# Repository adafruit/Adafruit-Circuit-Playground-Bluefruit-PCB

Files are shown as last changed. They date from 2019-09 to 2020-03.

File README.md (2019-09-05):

## Adafruit Adafruit Circuit Playground Bluefruit PCB

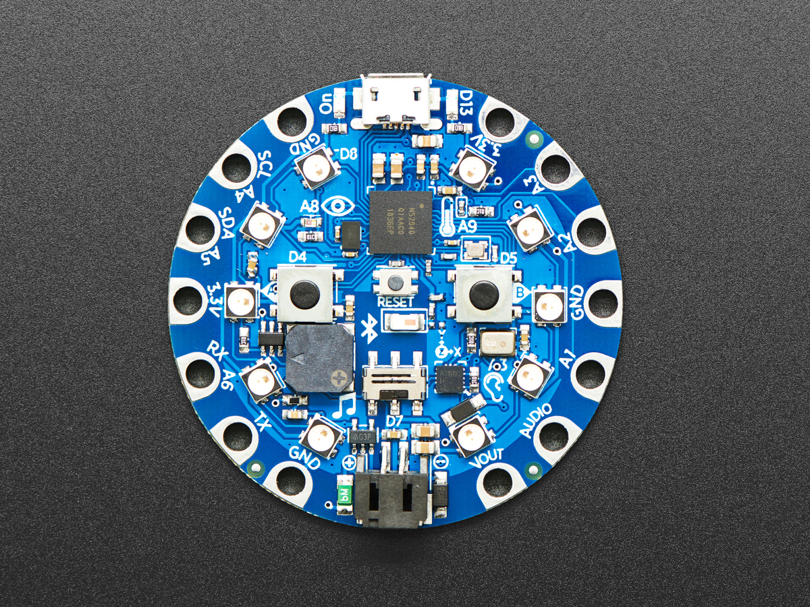
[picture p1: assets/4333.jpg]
<a href="http://www.adafruit.com/products/4333"><br/>
Click here to purchase one from the Adafruit shop</a>

PCB files for the Adafruit Adafruit Circuit Playground Bluefruit. 

Format is EagleCAD schematic and board layout
* https://www.adafruit.com/product/4333

### Description

Circuit Playground Bluefruit is our third board in the Circuit Playground series, another step towards a perfect introduction to electronics and programming. We've taken the popular Circuit Playground Express and made it even better! Now the main chip is an nRF52840 microcontroller which is not only more powerful, but also comes with Bluetooth Low Energy support for wireless connectivity.

The board is round and has alligator-clip pads around it so you don't have to solder or sew to make it work. You can power it from USB, a AAA battery pack, or with a Lipoly battery (for advanced users). Circuit Playground Bluefruit has built-in USB support. Built in USB means you plug it in to program it and it just shows up, no special cable or adapter required. Just program your code into the board then take it on the go!

Here's some of the great goodies baked in to each Circuit Playground Bluefruit:

* 1 x nRF52840 Cortex M4 processor with Bluetooth Low Energy support
* 10 x mini NeoPixels, each one can display any color
* 1 x Motion sensor (LIS3DH triple-axis accelerometer with tap detection, free-fall detection)
* 1 x Temperature sensor (thermistor)
* 1 x Light sensor (phototransistor). Can also act as a color sensor and pulse sensor.
* 1 x Sound sensor (MEMS microphone)
* 1 x Mini speaker with class D amplifier (7.5mm magnetic speaker/buzzer)
* 2 x Push buttons, labeled A and B
* 1 x Slide switch
* 8 x alligator-clip friendly input/output pins
* Includes I2C, UART, 6 pins that can do analog inputs, multiple PWM outputs
* Green "ON" LED so you know its powered
* Red "#13" LED for basic blinking
* Reset button
* 2 MB of SPI Flash storage, used primarily with CircuitPython to store code and libraries.
* MicroUSB port for programming and debugging
* USB port can act like serial port, keyboard, mouse, joystick or MIDI!

### License

Adafruit invests time and resources providing this open source design, please support Adafruit and open-source hardware by purchasing products from [Adafruit](https://www.adafruit.com)!

Designed by Limor Fried/Ladyada for Adafruit Industries.

Creative Commons Attribution/Share-Alike, all text above must be included in any redistribution. 
See license.txt for additional details.

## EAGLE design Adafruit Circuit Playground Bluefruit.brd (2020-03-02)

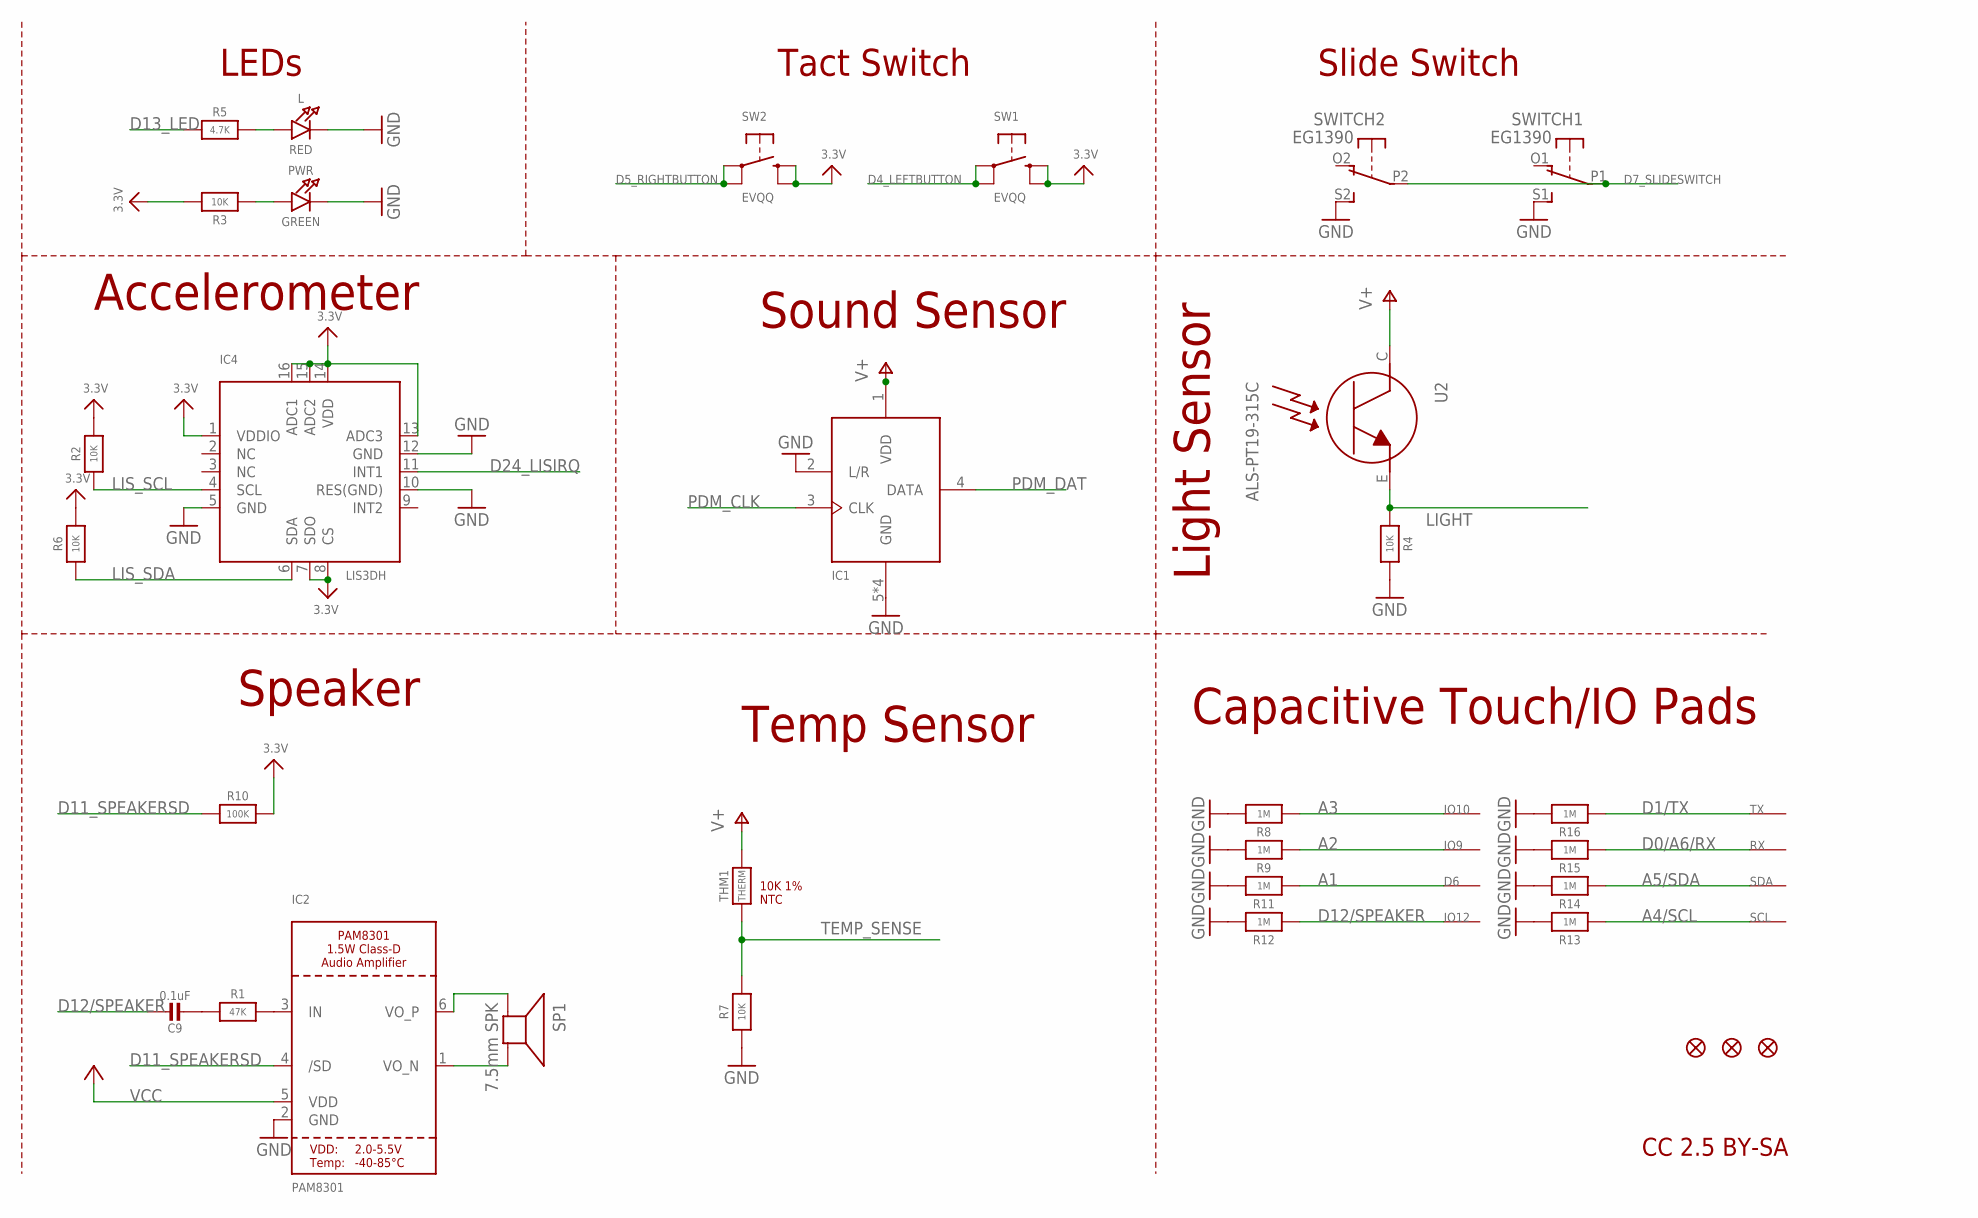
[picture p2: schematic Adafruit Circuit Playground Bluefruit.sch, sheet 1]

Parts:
C9: 0.1uF; 0603-NO
D6: SEWTAP-ALLIGATOR; SEWALLI
IC1: MIC_PDM; SPK0415HM4H
IC2: PAM8301; SOT23-6
IC4: LIS3DH; LGA16_3X3MM
IO9, IO10, IO12: SEWTAP-ALLIGATOR; SEWALLI
L: RED; CHIPLED_0603_NOOUTLINE
PWR: GREEN; CHIPLED_0603_NOOUTLINE
R1: 47K; 0603-NO
R2, R3, R4, R6, R7: 10K; 0603-NO
R5: 4.7K; 0603-NO
R8, R9, R11, R12, R13, R14, R15, R16: 1M; 0603-NO
R10: 100K; 0603-NO
RX: SEWTAP-ALLIGATOR; SEWALLI
SCL: SEWTAP-ALLIGATOR; SEWALLI
SDA: SEWTAP-ALLIGATOR; SEWALLI
SP1: 7.5mm SPK; BUZZER_SMT_7.5MM
SW1, SW2: EVQQ; EVQ-Q2_SMALLER
SWITCH: EG1390
THM1: THERM; _0402
TX: SEWTAP-ALLIGATOR; SEWALLI
U2: ALS-PT19-315C
U$2, U$3, U$6: FIDUCIAL_1MM

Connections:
3.3V: IC4.1 (VDDIO), IC4.7 (SDO), IC4.8 (CS), IC4.13 (ADC3), IC4.14 (VDD), IC4.15 (ADC2), IC4.16 (ADC1), R2.2, R3.2, R6.2, R10.2, SW1.B (S), SW1.B' (S1), SW2.B (S), SW2.B' (S1); also elsewhere on the board
A1: D6.P$1, R11.1; also elsewhere on the board
A2: IO9.P$1, R9.1; also elsewhere on the board
A3: IO10.P$1, R8.1; also elsewhere on the board
A4/SCL: R13.1, SCL.P$1; also elsewhere on the board
A5/SDA: R14.1, SDA.P$1; also elsewhere on the board
D0/A6/RX: R15.1, RX.P$1; also elsewhere on the board
D1/TX: R16.1, TX.P$1; also elsewhere on the board
D4_LEFTBUTTON: SW1.A, SW1.A' (P1); also elsewhere on the board
D5_RIGHTBUTTON: SW2.A, SW2.A' (P1); also elsewhere on the board
D7_SLIDESWITCH: SWITCH.P1, SWITCH.P2; also elsewhere on the board
D11_SPEAKERSD: IC2.4 (/SD), R10.1; also elsewhere on the board
D12/SPEAKER: C9.1, IO12.P$1, R12.1; also elsewhere on the board
D13_LED: R5.1; also elsewhere on the board
D24_LISIRQ: IC4.11 (INT1); also elsewhere on the board
GND: IC1.2 (L/R), IC1.5 (GND), IC1.6 (GND), IC1.7 (GND), IC1.8 (GND), IC2.2 (GND), IC4.5 (GND), IC4.10 (RES(GND)), IC4.12 (GND), L.C, PWR.C, R4.1, R7.1, R8.2, R9.2, R11.2, R12.2, R13.2, R14.2, R15.2, R16.2, SWITCH.S1 (S), SWITCH.S2 (S); also elsewhere on the board
LIGHT: R4.2, U2.E; also elsewhere on the board
LIS_SCL: IC4.4 (SCL), R2.1; also elsewhere on the board
LIS_SDA: IC4.6 (SDA), R6.1; also elsewhere on the board
unnamed: PWR.A, R3.1
unnamed: C9.2, R1.1
unnamed: IC2.3 (IN), R1.2
unnamed: IC2.6 (VO_P), SP1.+
unnamed: L.A, R5.2
unnamed: IC2.1 (VO_N), SP1.-
PDM_CLK: IC1.3 (CLK); also elsewhere on the board
PDM_DAT: IC1.4 (DATA); also elsewhere on the board
TEMP_SENSE: R7.2, THM1.1; also elsewhere on the board
V+: IC1.1 (VDD), THM1.2, U2.C; also elsewhere on the board
VCC: IC2.5 (VDD); also elsewhere on the board

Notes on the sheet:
CC 2.5 BY-SA
10K 1% NTC
Speaker
Temp Sensor
Light Sensor
Sound Sensor
Slide Switch
Tact Switch
LEDs
Accelerometer
Capacitive Touch/IO Pads

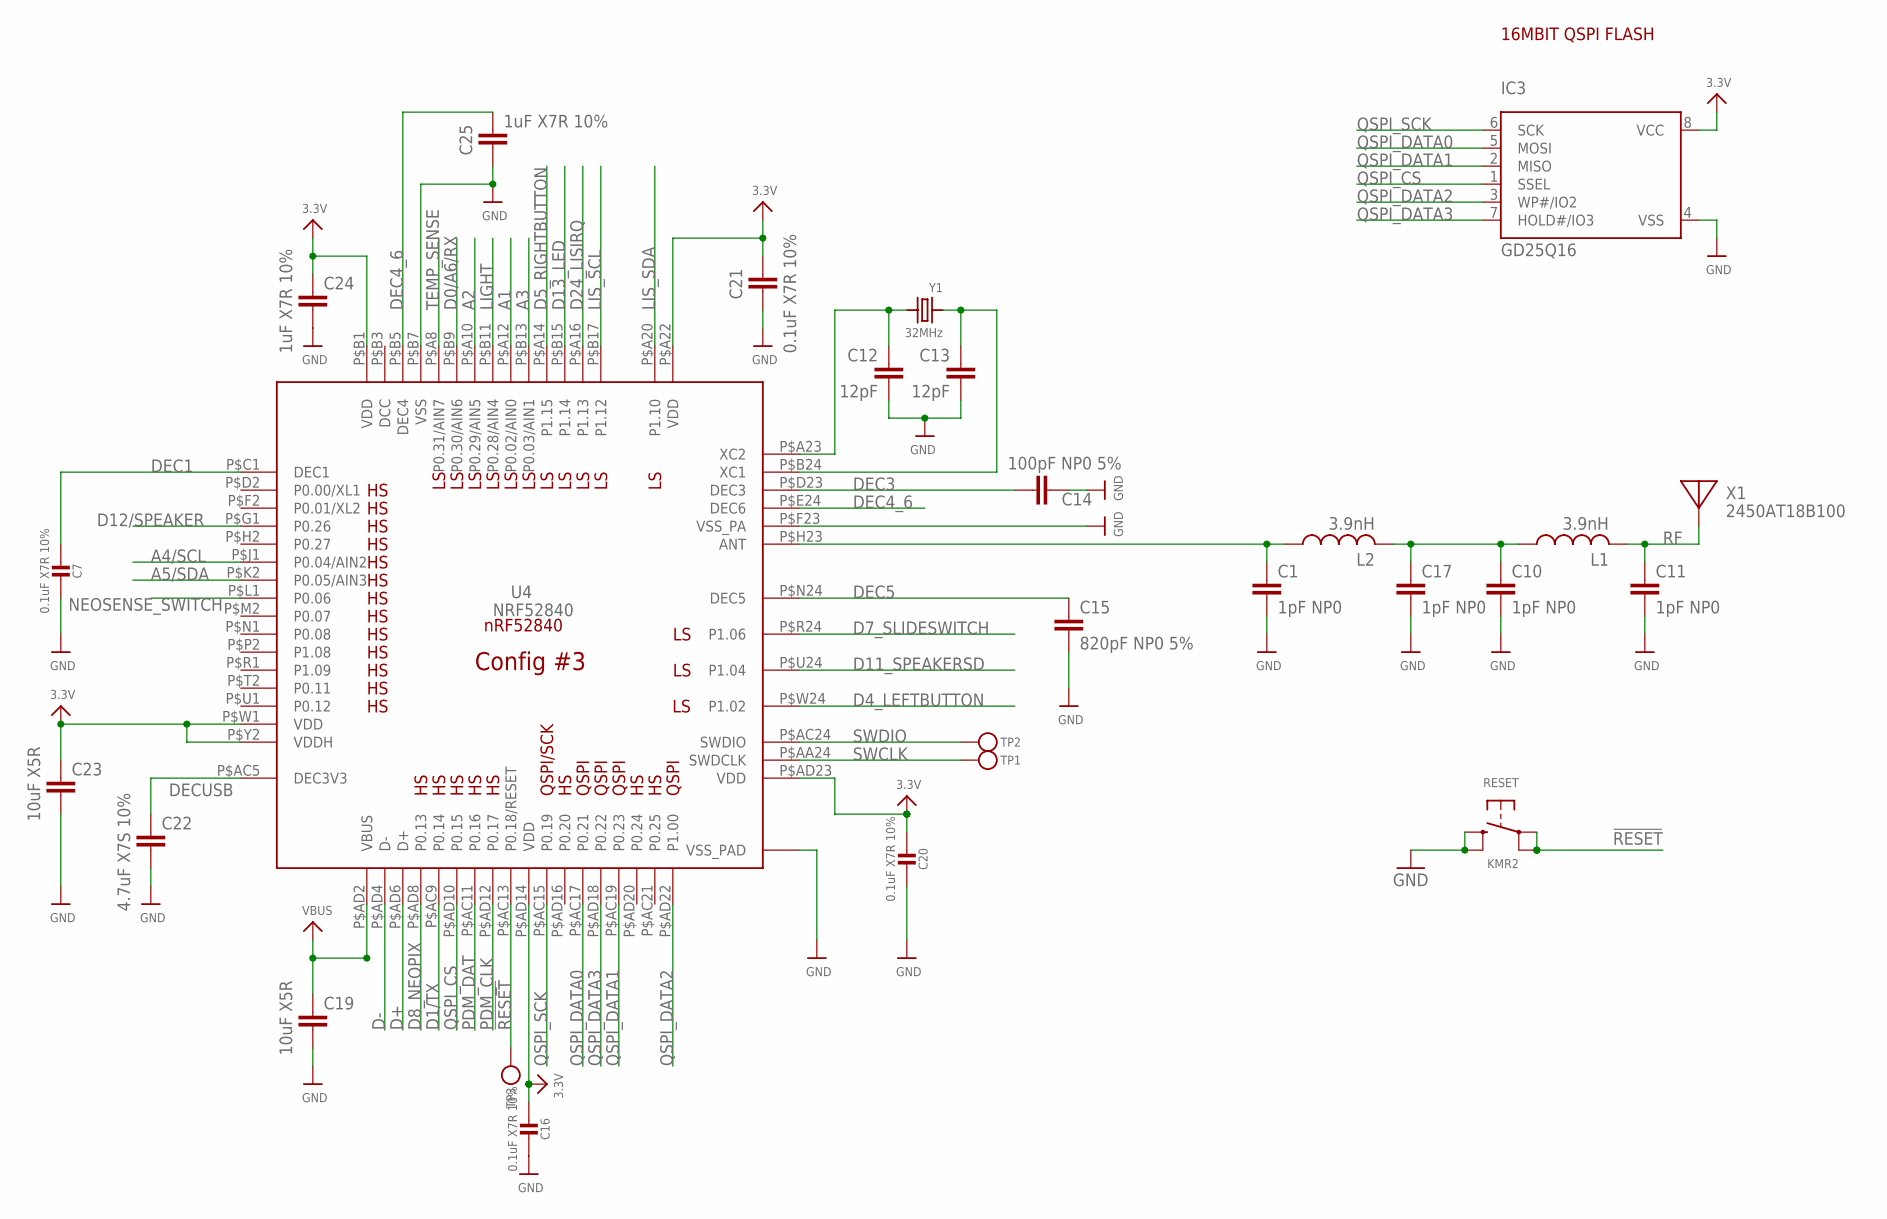
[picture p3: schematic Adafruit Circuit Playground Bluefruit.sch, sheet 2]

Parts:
C1, C10, C11, C17: 1pF NP0; RESC0402_N
C7, C16, C20: 0.1uF X7R 10%; 0603-NO
C12, C13: 12pF; RESC0402_N
C14: 100pF NP0 5%; RESC0402_N
C15: 820pF NP0 5%; RESC0402_N
C19, C23: 10uF X5R; RESC0805_N
C21: 0.1uF X7R 10%; RESC0603_L
C22: 4.7uF X7S 10%; RESC0805_N
C24, C25: 1uF X7R 10%; RESC0603_N
IC3: GD25Q16; USON8
L1, L2: 3.9nH; RESC0402_N
RESET: KMR2; BTN_KMR2_4.6X2.8
TP1, TP2, TP3: TESTPOINTROUND1.5MMNO; TESTPOINT_ROUND_1.5MM_NO
U4: NRF52840; AQFN50P700X800X85_HS-74N_SMALLCENTER
X1: 2450AT18B100; ANT_2450AT18B100
Y1: 32MHz; CRYSTAL_2X1.6

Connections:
3.3V: C16.2, C20.2, C21.1, C23.1, C24.1, IC3.8 (VCC), U4.P$A22 (VDD), U4.P$AD14 (VDD), U4.P$AD23 (VDD), U4.P$B1 (VDD), U4.P$W1 (VDD), U4.P$Y2 (VDDH); also elsewhere on the board
!RESET: RESET.A, RESET.A' (P1), TP3.P$1, U4.P$AC13 (P0.18/RESET)
A1: U4.P$A12 (P0.02/AIN0); also elsewhere on the board
A2: U4.P$A10 (P0.29/AIN5); also elsewhere on the board
A3: U4.P$B13 (P0.03/AIN1); also elsewhere on the board
A4/SCL: U4.P$J1 (P0.04/AIN2); also elsewhere on the board
A5/SDA: U4.P$K2 (P0.05/AIN3); also elsewhere on the board
D0/A6/RX: U4.P$B9 (P0.30/AIN6); also elsewhere on the board
D1/TX: U4.P$AC9 (P0.14); also elsewhere on the board
D4_LEFTBUTTON: U4.P$W24 (P1.02); also elsewhere on the board
D5_RIGHTBUTTON: U4.P$A14 (P1.15); also elsewhere on the board
D7_SLIDESWITCH: U4.P$R24 (P1.06); also elsewhere on the board
D8_NEOPIX: U4.P$AD8 (P0.13); also elsewhere on the board
D11_SPEAKERSD: U4.P$U24 (P1.04); also elsewhere on the board
D12/SPEAKER: U4.P$G1 (P0.26); also elsewhere on the board
D13_LED: U4.P$B15 (P1.14); also elsewhere on the board
D24_LISIRQ: U4.P$A16 (P1.13); also elsewhere on the board
D+: U4.P$AD6 (D+); also elsewhere on the board
D-: U4.P$AD4 (D-); also elsewhere on the board
DEC1: C7.2, U4.P$C1 (DEC1)
DEC3: C14.1, U4.P$D23 (DEC3)
DEC4_6: C25.1, U4.P$B5 (DEC4), U4.P$E24 (DEC6)
DEC5: C15.1, U4.P$N24 (DEC5)
DECUSB: C22.1, U4.P$AC5 (DEC3V3)
GND: C1.2, C7.1, C10.2, C11.2, C12.2, C13.2, C14.2, C15.2, C16.1, C17.2, C19.2, C20.1, C21.2, C22.2, C23.2, C24.2, C25.2, IC3.4 (VSS), RESET.B (S), RESET.B' (S1), U4.P$B7 (VSS), U4.P$F23 (VSS_PA), U4.THERMPAD (VSS_PAD); also elsewhere on the board
LIGHT: U4.P$B11 (P0.28/AIN4); also elsewhere on the board
LIS_SCL: U4.P$B17 (P1.12); also elsewhere on the board
LIS_SDA: U4.P$A20 (P1.10); also elsewhere on the board
unnamed: C1.1, L2.1, U4.P$H23 (ANT)
unnamed: C12.1, U4.P$A23 (XC2), Y1.3 (2)
unnamed: C13.1, U4.P$B24 (XC1), Y1.1
NEOSENSE_SWITCH: U4.P$L1 (P0.06); also elsewhere on the board
PDM_CLK: U4.P$AD12 (P0.17); also elsewhere on the board
PDM_DAT: U4.P$AC11 (P0.16); also elsewhere on the board
QSPI_CS: IC3.1 (SSEL), U4.P$AD10 (P0.15)
QSPI_DATA0: IC3.5 (MOSI), U4.P$AC17 (P0.21)
QSPI_DATA1: IC3.2 (MISO), U4.P$AC19 (P0.23)
QSPI_DATA2: IC3.3 (WP#/IO2), U4.P$AD22 (P1.00)
QSPI_DATA3: IC3.7 (HOLD#/IO3), U4.P$AD18 (P0.22)
QSPI_SCK: IC3.6 (SCK), U4.P$AC15 (P0.19)
RF: C11.1, L1.2, X1.FP
RF1: C10.1, C17.1, L1.1, L2.2
SWCLK: TP1.P$1, U4.P$AA24 (SWDCLK)
SWDIO: TP2.P$1, U4.P$AC24 (SWDIO)
TEMP_SENSE: U4.P$A8 (P0.31/AIN7); also elsewhere on the board
VBUS: C19.1, U4.P$AD2 (VBUS); also elsewhere on the board

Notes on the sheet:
16MBIT QSPI FLASH
Config #3

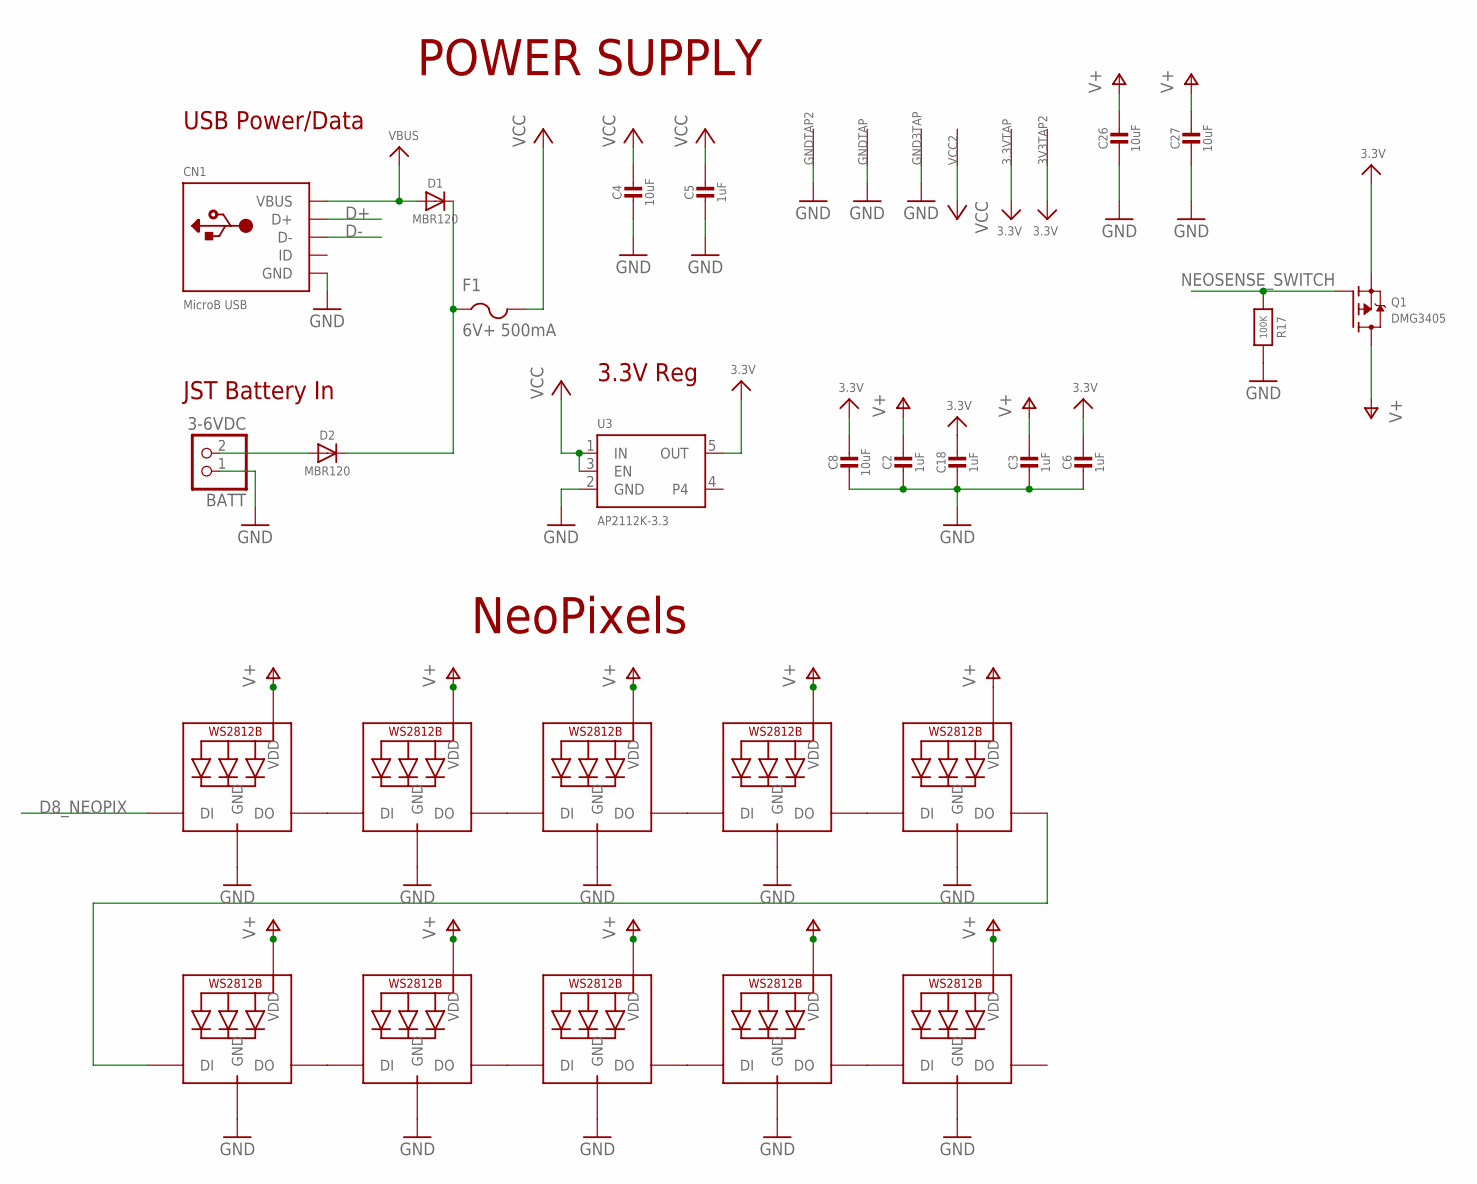
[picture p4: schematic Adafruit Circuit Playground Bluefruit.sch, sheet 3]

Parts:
3.3VTAP, 3V3TAP2: SEWTAP-ALLIGATOR; SEWALLI
BATT: 3-6VDC; JSTPH2
C2, C3, C5, C6, C18: 1uF; 0603-NO
C4, C8, C26, C27: 10uF; 0805-NO
CN1: MicroB USB; 4UCONN_20329_V2
D1, D2: MBR120; SOD-123
F1: 6V+ 500mA; R1206
GND3TAP: SEWTAP-ALLIGATOR; SEWALLI
GNDTAP, GNDTAP2: SEWTAP-ALLIGATOR; SEWALLI
LED1, LED2, LED3, LED4, LED5, LED6, LED7, LED8, LED9, LED10: WS2812B3535; LED3535
Q1: DMG3405; SOT23-R
R17: 100K; 0603-NO
U3: AP2112K-3.3; SOT23-5
VCC2: SEWTAP-ALLIGATOR; SEWALLI

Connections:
3.3V: 3.3VTAP.P$1, 3V3TAP2.P$1, C6.1, C8.1, C18.1, Q1.2 (S), U3.5 (OUT); also elsewhere on the board
D8_NEOPIX: LED6.1 (DI); also elsewhere on the board
D+: CN1.D+; also elsewhere on the board
D-: CN1.D-; also elsewhere on the board
GND: BATT.1, C2.2, C3.2, C4.2, C5.2, C6.2, C8.2, C18.2, C26.2, C27.2, CN1.BASE@1 (GND), CN1.BASE@2 (GND), CN1.GND, CN1.SPRT@1 (GND), CN1.SPRT@2 (GND), CN1.SPRT@3 (GND), CN1.SPRT@4 (GND), GND3TAP.P$1, GNDTAP.P$1, GNDTAP2.P$1, LED1.4 (GND), LED2.4 (GND), LED3.4 (GND), LED4.4 (GND), LED5.4 (GND), LED6.4 (GND), LED7.4 (GND), LED8.4 (GND), LED9.4 (GND), LED10.4 (GND), R17.2, U3.2 (GND); also elsewhere on the board
unnamed: D1.C, D2.C, F1.1
unnamed: BATT.2, D2.A
unnamed: LED1.1 (DI), LED2.3 (DO)
unnamed: LED1.3 (DO), LED3.1 (DI)
unnamed: LED2.1 (DI), LED10.3 (DO)
unnamed: LED6.3 (DO), LED7.1 (DI)
unnamed: LED7.3 (DO), LED8.1 (DI)
unnamed: LED8.3 (DO), LED9.1 (DI)
unnamed: LED9.3 (DO), LED10.1 (DI)
unnamed: LED3.3 (DO), LED4.1 (DI)
unnamed: LED4.3 (DO), LED5.1 (DI)
NEOSENSE_SWITCH: Q1.1 (G), R17.1; also elsewhere on the board
V+: C2.1, C3.1, C26.1, C27.1, LED1.2 (VDD), LED2.2 (VDD), LED3.2 (VDD), LED4.2 (VDD), LED5.2 (VDD), LED6.2 (VDD), LED7.2 (VDD), LED8.2 (VDD), LED9.2 (VDD), LED10.2 (VDD), Q1.3 (D); also elsewhere on the board
VBUS: CN1.VBUS, D1.A; also elsewhere on the board
VCC: C4.1, C5.1, F1.2, U3.1 (IN), U3.3 (EN), VCC2.P$1; also elsewhere on the board

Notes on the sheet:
NeoPixels
USB Power/Data
JST Battery In
3.3V Reg
POWER SUPPLY

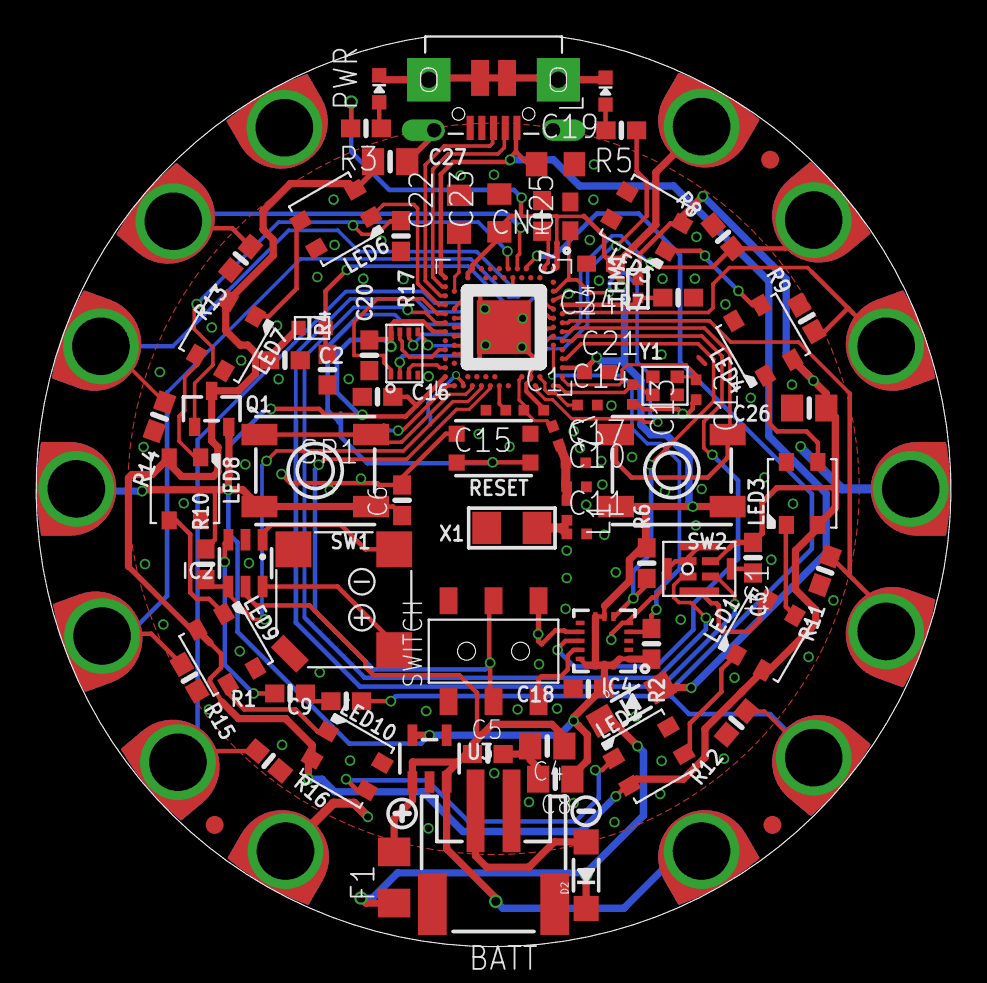
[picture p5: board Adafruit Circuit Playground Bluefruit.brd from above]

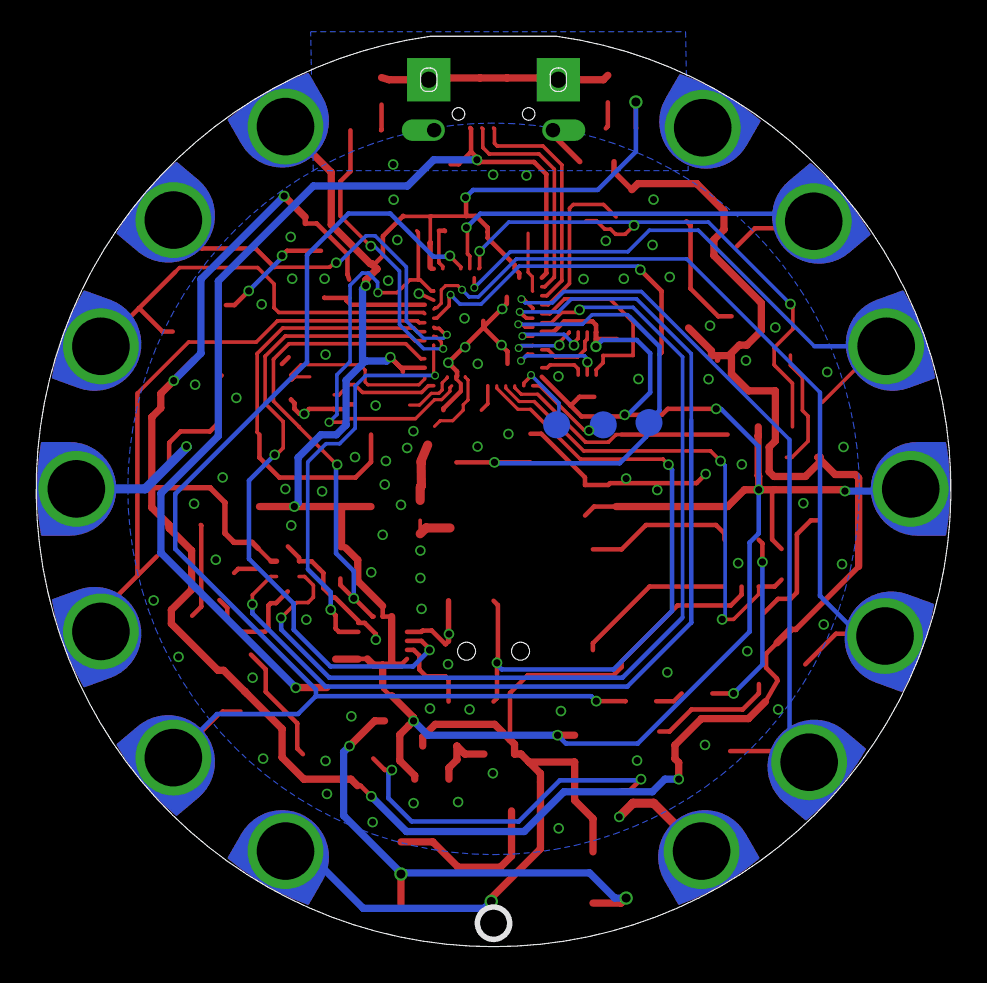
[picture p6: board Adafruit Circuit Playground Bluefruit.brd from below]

Board: 2 copper layers, 50.8 x 50.6 mm, 104 parts (5 on the bottom side), 65 nets.

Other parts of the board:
U$1: SYMBOL_MINUS
U$7: PCBFEAT-REV-040
U$16: CPLAY_BLUEFRUIT_BOT
U$35: SYMBOL_PLUS
U$44: CPLAY_BLUEFRUIT_TOP

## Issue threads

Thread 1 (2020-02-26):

Please update schematic, adding POWER_SWITCH changes

urish, 2020-02-26:
We're looking to include some Bluefruit boards in our next [CircuitPython Workshop](https://www.meetup.com/IoT-Makers-Israel/events/267224629/).

They are not available for purchase on DigiKey Israel, and out of stock on Adafruit's site, so we're considering making a small batch of the PCB and assembling here, especially for the workshop.

By making our batch we will also be able to put sponsor logo on the PCB (making it easier for us to find a sponsor), and perhaps also upgrade to Micro USB to USB Type-C port. We will share the modified version, respecting the [terms of the license](https://github.com/adafruit/Adafruit-Circuit-Playground-Bluefruit-PCB/blob/b482caa5d5163efdda080e9e892c69210677a284/license.txt), of course.

Can you please update the board eagle files with the latest revision, with the [`POWER_SWITCH` pin](https://github.com/adafruit/circuitpython/blob/3dc98a7a795fd93dce7fb133cf504cd8dffb882d/ports/nrf/boards/circuitplayground_bluefruit/pins.c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)?

Your help here will be greatly appreciated!

kattni, 2020-03-02:
@urish I've uploaded the latest rev of the board.

urish, 2020-03-02:
Thank you so much @kattni !

kattni, 2020-03-02:
@urish You're entirely welcome :)

Closed 2020-03-02.

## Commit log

2019-09-05 Adding PCB files.
    [Adafruit Circuit Playground Bluefruit.brd, Adafruit Circuit Playground Bluefruit.sch]
2020-03-02 Deleting previous rev.
    [Adafruit Circuit Playground Bluefruit.brd]
2020-03-02 Upload new board files.
    [Adafruit Circuit Playground Bluefruit.brd, Adafruit Circuit Playground Bluefruit.sch]
2021-05-15 Add pin reference PDF

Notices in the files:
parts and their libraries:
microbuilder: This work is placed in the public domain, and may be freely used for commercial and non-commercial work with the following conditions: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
